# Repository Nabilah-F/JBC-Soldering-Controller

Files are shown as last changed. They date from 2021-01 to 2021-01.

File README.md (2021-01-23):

# JBC-Soldering-Controller

The idea of this project is to make a JBC soldering station for the T245, T210, HT420 and PA120 Micro Tweezers. 
It runs from a 12V to 24V DC power supply.

Tested:

T245 soldering iron

Todo:

Automatically changing the GUI depending on if you are using the standard iron or the tweezers.
Update FW to use tweezers.

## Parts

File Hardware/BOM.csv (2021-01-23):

Reference | Quantity | Value | Footprint | Datasheet
C1 C2 C4 C5 | 4 | 0.047uF | Capacitor_SMD:C_0805_2012Metric_Pad1.15x1.40mm_HandSolder | ~
C10 | 1 | 20uF | Capacitor_SMD:C_0805_2012Metric_Pad1.15x1.40mm_HandSolder | ~
C11 C14 C17 C18 C19 | 5 | 10nF | Capacitor_SMD:C_0805_2012Metric_Pad1.15x1.40mm_HandSolder | ~
C21 | 1 | 1uF | Capacitor_SMD:C_0805_2012Metric_Pad1.15x1.40mm_HandSolder | ~
C3 C6 | 2 | 0.47uF | Capacitor_SMD:C_0805_2012Metric_Pad1.15x1.40mm_HandSolder | ~
C7 C20 C9 C12 C13 C15 C16 | 7 | 0.1uF | Capacitor_SMD:C_0805_2012Metric_Pad1.15x1.40mm_HandSolder | ~
C8 | 1 | 10uF | Capacitor_SMD:C_0805_2012Metric_Pad1.15x1.40mm_HandSolder | ~
D1 | 1 | 1N4448 | Diode_SMD:D_SOD-123F | http://www.nxp.com/documents/data_sheet/1N4148_1N4448.pdf
D10 D11 D8 D9 | 4 | 4V7 | Diode_SMD:D_SOD-123 | ~
D2 | 1 | B140-E3 | Diode_SMD:D_SMA | http://www.vishay.com/docs/88946/b120.pdf
D3 D4 | 2 | WS2812B | LED_SMD:LED_WS2812B_PLCC4_5.0x5.0mm_P3.2mm | https://cdn-shop.adafruit.com/datasheets/WS2812B.pdf
D5 | 1 | LED | LED_SMD:LED_0603_1608Metric_Pad1.05x0.95mm_HandSolder | ~
D6 D7 | 2 | D | Diode_SMD:D_SOD-123F | ~
J1 J2 | 2 | JBC_iron | Connector_Phoenix_MSTB:PhoenixContact_MSTBVA_2,5_3-G-5,08_1x03_P5.08mm_Vertical
J3 J7 | 2 | Conn_01x01 | Connector_PinHeader_2.54mm:PinHeader_1x01_P2.54mm_Vertical | ~
J4 | 1 | Barrel_Jack_Switch | Connector_BarrelJack:BarrelJack_Horizontal | ~
J6 | 1 | Audio-Jack-3 | footprints:Jack_3.5mm_Horizontal
L1 | 1 | 22uH | Inductor_SMD:L_6.3x6.3_H3
Q1 Q2 | 2 | Q_NMOS_GSD | Package_TO_SOT_SMD:TO-263-2 | ~
R1 R2 R5 R6 | 4 | 100k | Resistor_SMD:R_0805_2012Metric_Pad1.15x1.40mm_HandSolder | ~
R13 | 1 | 52.3k | Resistor_SMD:R_0805_2012Metric_Pad1.15x1.40mm_HandSolder | ~
R14 R16 R19 R23 R24 R25 R26 R35 R36 | 9 | 10k | Resistor_SMD:R_0805_2012Metric_Pad1.15x1.40mm_HandSolder | ~
R15 | 1 | 0R | Resistor_SMD:R_0805_2012Metric_Pad1.15x1.40mm_HandSolder | ~
R17 R20 | 2 | 750R | Resistor_SMD:R_0805_2012Metric_Pad1.15x1.40mm_HandSolder | ~
R18 R21 | 2 | 1k2 | Resistor_SMD:R_0805_2012Metric_Pad1.15x1.40mm_HandSolder | ~
R22 | 1 | 330 | Resistor_SMD:R_0805_2012Metric_Pad1.15x1.40mm_HandSolder | ~
R27 R30 R31 R32 | 4 | 100 | Resistor_SMD:R_0805_2012Metric_Pad1.15x1.40mm_HandSolder | ~
R28 | 1 | 30k | Resistor_SMD:R_0805_2012Metric_Pad1.15x1.40mm_HandSolder | ~
R29 | 1 | 5k1 | Resistor_SMD:R_0805_2012Metric_Pad1.15x1.40mm_HandSolder | ~
R3 R4 R7 R8 | 4 | 820 | Resistor_SMD:R_0805_2012Metric_Pad1.15x1.40mm_HandSolder | ~
R33 R34 | 2 | DNF | Resistor_SMD:R_0805_2012Metric_Pad1.15x1.40mm_HandSolder | ~
R9 R10 R11 R12 | 4 | 51 | Resistor_SMD:R_0805_2012Metric_Pad1.15x1.40mm_HandSolder | ~
SW1 | 1 | Rotary_Encoder_Switch | footprints:rot_encoder_alt | ~
TP1 TP2 TP3 TP4 | 4 | TestPoint | TestPoint:TestPoint_Keystone_5005-5009_Compact | ~
U1 | 1 | OLED_I2C_128x32 | footprints:OLED_I2C_128x32_alt
U10 | 1 | 74LVC1G32 | Package_TO_SOT_SMD:SOT-23-5_HandSoldering | http://www.ti.com/lit/sg/scyt129e/scyt129e.pdf
U2 | 1 | arduino_pro_micro | Package_DIP:DIP-24_W15.24mm_LongPads
U3 | 1 | ADS1120-PW | Package_SO:TSSOP-16_4.4x5mm_P0.65mm | http://www.ti.com/lit/ds/symlink/ads1120.pdf
U4 | 1 | MCP16301 | Package_TO_SOT_SMD:SOT-23-6_Handsoldering
U5 | 1 | AD586 | Package_SO:SOIC-8-1EP_3.9x4.9mm_P1.27mm_EP2.35x2.35mm | http://www.analog.com/media/en/technical-documentation/data-sheets/AD586.pdf
U6 U7 | 2 | VN5E010 | footprints:HPAK
U8 U9 | 2 | FODM3011 | Package_DIP:SMDIP-4_W7.62mm | http://www.fairchildsemi.com/ds/FO/FODM3053.pdf

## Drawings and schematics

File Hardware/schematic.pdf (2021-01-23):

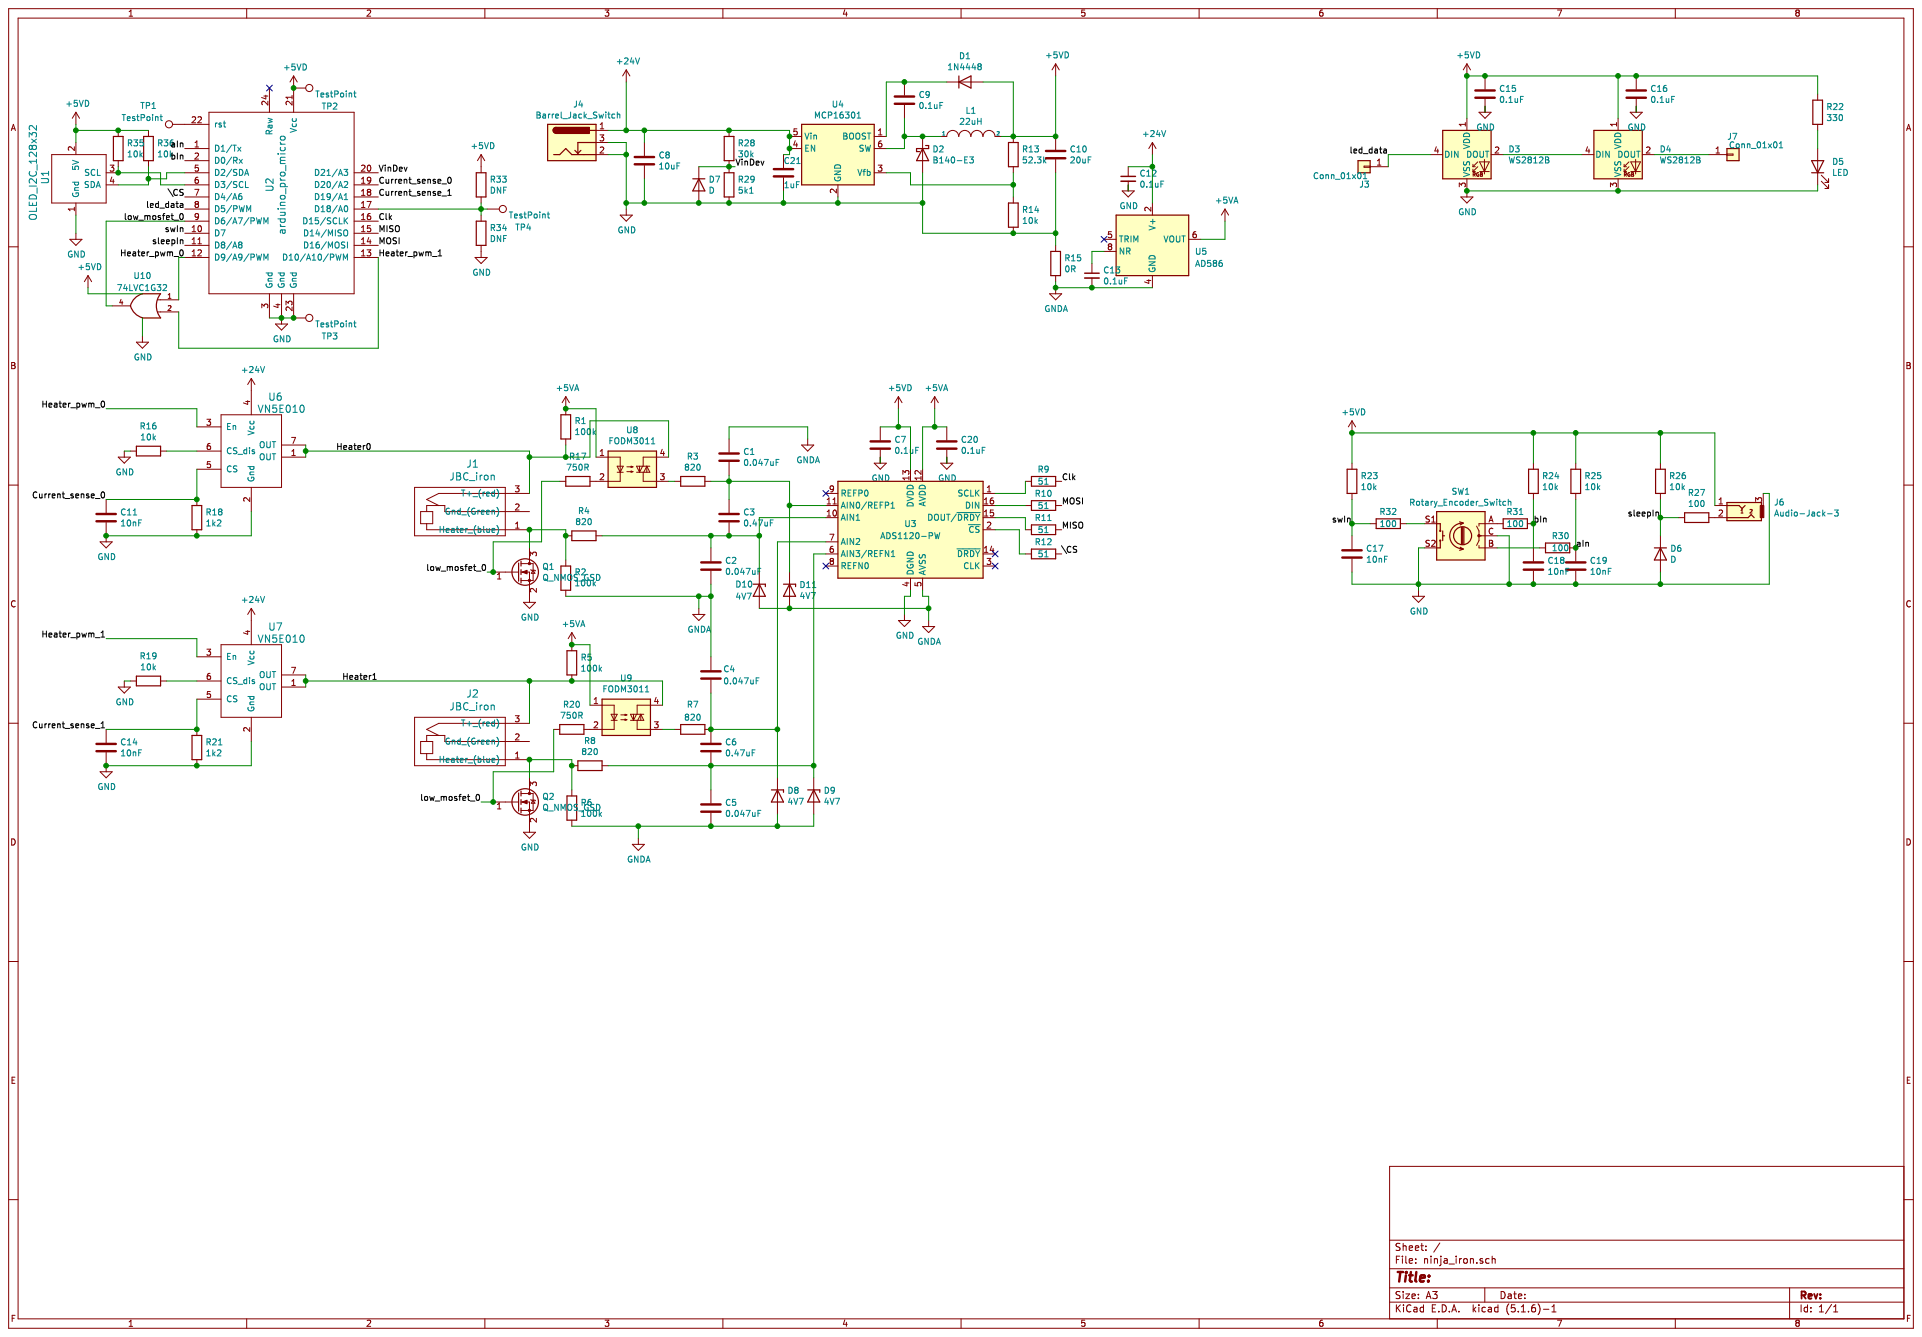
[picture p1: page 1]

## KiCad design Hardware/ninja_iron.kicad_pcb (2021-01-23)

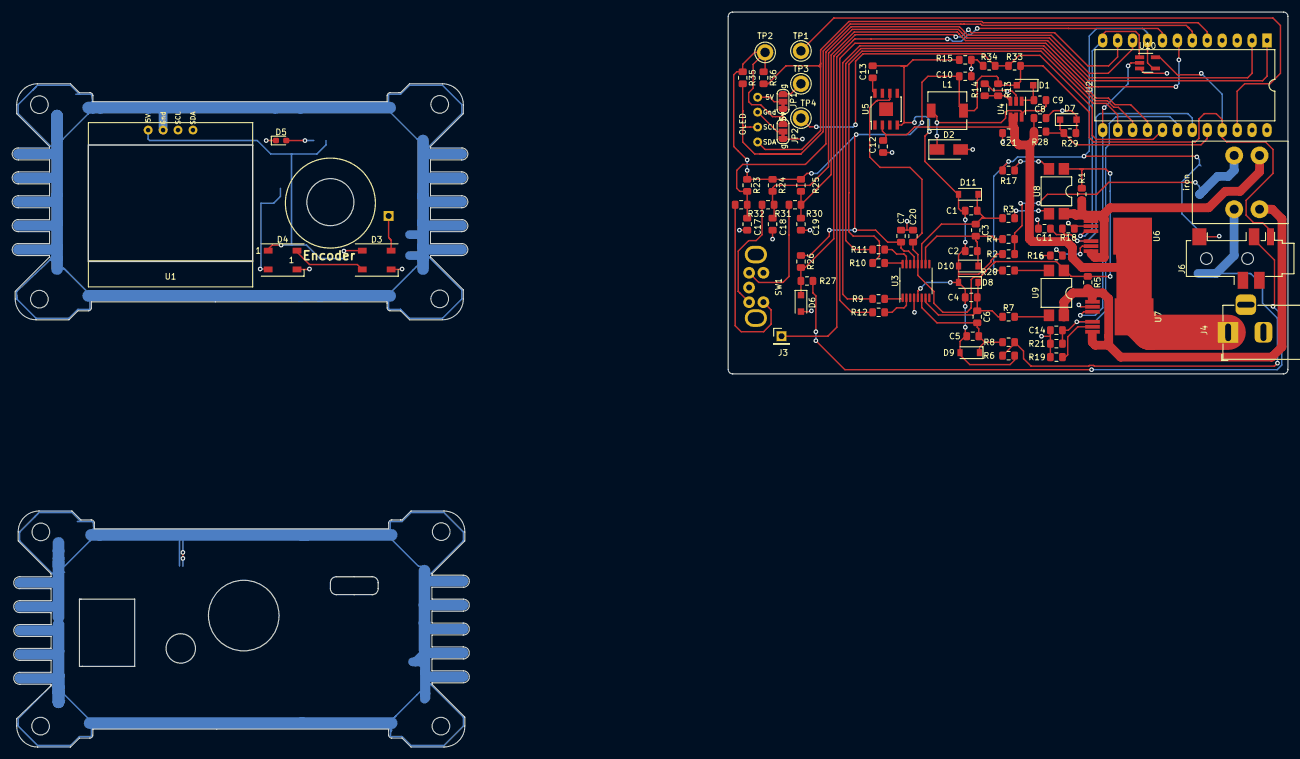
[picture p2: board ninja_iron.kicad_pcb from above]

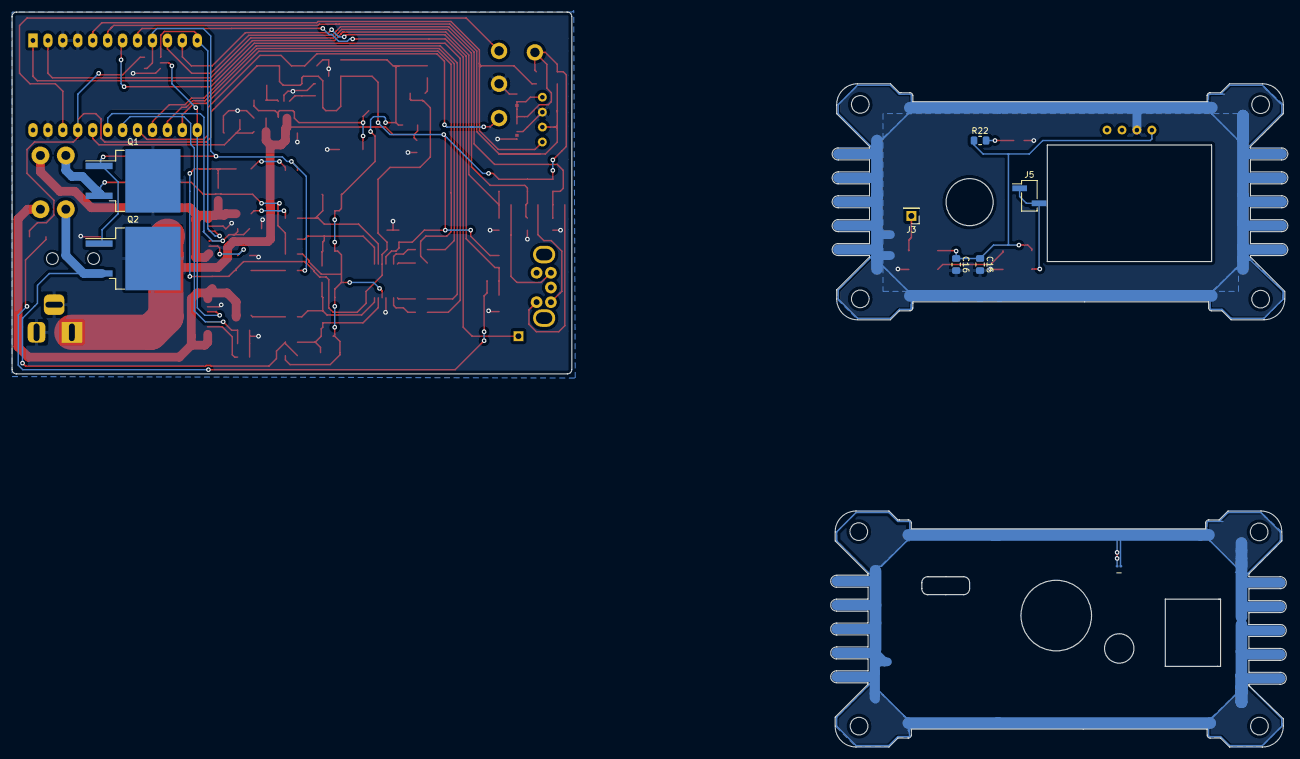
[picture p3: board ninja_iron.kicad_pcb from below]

Board: 2 copper layers, 95.2 x 61.5 mm, 96 parts (8 on the bottom side), 52 nets.

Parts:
-: R_0201_0603Metric
C1, C2, C4, C5: 0.047uF; C_0805_2012Metric_Pad1.15x1.40mm_HandSolder
C3, C6: 0.47uF; C_0805_2012Metric_Pad1.15x1.40mm_HandSolder
C7, C9, C12, C13, C15, C16, C20: 0.1uF; C_0805_2012Metric_Pad1.15x1.40mm_HandSolder
C8: 10uF; C_0805_2012Metric_Pad1.15x1.40mm_HandSolder
C10: 20uF; C_0805_2012Metric_Pad1.15x1.40mm_HandSolder
C11, C14, C17, C18, C19: 10nF; C_0805_2012Metric_Pad1.15x1.40mm_HandSolder
C21: 1uF; C_0805_2012Metric_Pad1.15x1.40mm_HandSolder
D1: 1N4448; D_SOD-123F
D2: B140-E3; D_SMA
D3, D4: WS2812B; LED_WS2812B_PLCC4_5.0x5.0mm_P3.2mm
D5: LED; LED_0603_1608Metric_Pad1.05x0.95mm_HandSolder
D6, D7: D; D_SOD-123F
D8, D9, D10, D11: 4V7; D_SOD-123
J3, J3#2: Conn_01x01; PinHeader_1x01_P2.54mm_Vertical
J4: Barrel_Jack_Switch; BarrelJack_Horizontal
J5: Conn_01x01; PinHeader_1x02_P2.54mm_Vertical_SMD_Pin1Left
J6: Audio-Jack-3; Jack_3.5mm_Horizontal
JP1, JP2: -; SolderJumper-3_P1.3mm_Bridged12_RoundedPad1.0x1.5mm_NumberL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
L1: 22uH; L_6.3x6.3_H3
OLED: pin_oled
Q1, Q2: Q_NMOS_GSD; TO-263-2
R1, R2, R5, R6: 100k; R_0805_2012Metric_Pad1.15x1.40mm_HandSolder
R3, R4, R7, R8: 820; R_0805_2012Metric_Pad1.15x1.40mm_HandSolder
R9, R10, R11, R12: 51; R_0805_2012Metric_Pad1.15x1.40mm_HandSolder
R13: 52.3k; R_0805_2012Metric_Pad1.15x1.40mm_HandSolder
R14, R16, R19, R23, R24, R25, R26, R35, R36: 10k; R_0805_2012Metric_Pad1.15x1.40mm_HandSolder
R15: 0R; R_0805_2012Metric_Pad1.15x1.40mm_HandSolder
R17, R20: 750R; R_0805_2012Metric_Pad1.15x1.40mm_HandSolder
R18, R21: 1k2; R_0805_2012Metric_Pad1.15x1.40mm_HandSolder
R22: 330; R_0805_2012Metric_Pad1.15x1.40mm_HandSolder
R27, R30, R31, R32: 100; R_0805_2012Metric_Pad1.15x1.40mm_HandSolder
R28: 30k; R_0805_2012Metric_Pad1.15x1.40mm_HandSolder
R29: 5k1; R_0805_2012Metric_Pad1.15x1.40mm_HandSolder
R33, R34: DNF; R_0805_2012Metric_Pad1.15x1.40mm_HandSolder
SW1: Rotary_Encoder_Switch; rot_encoder_alt
TP1, TP2, TP3, TP4: TestPoint; TestPoint_Keystone_5005-5009_Compact
U1: OLED_I2C_128x32; OLED_I2C_128x32_alt
U2: arduino_pro_micro; DIP-24_W15.24mm_LongPads
U3: ADS1120-PW; TSSOP-16_4.4x5mm_P0.65mm
U4: MCP16301; SOT-23-6_Handsoldering
U5: AD586; SOIC-8-1EP_3.9x4.9mm_P1.27mm_EP2.35x2.35mm
U6, U7: VN5E010; HPAK
U8, U9: FODM3011; SMDIP-4_W7.62mm
U10: 74LVC1G32; SOT-23-5_HandSoldering
iron: neutrik_modified

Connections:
+5VA: C20.1, R1.2, R5.1, U3.12, U5.6, U8.1, U9.1
+5VD: C7.1, C10.1, C15.1, C16.1, D1.2, D3.1, D4.1, J6.1, JP1.1, JP1.2, JP2.3, L1.2, OLED.1, R13.1, R22.1, R23.1, R24.1, R25.1, R26.1, R33.1, R35.1, R36.1, TP2.1, U1.1, U2.21, U3.13, U10.5
+24V: C8.1, C12.1, C21.1, J4.1, R28.1, U4.4, U4.5, U5.2, U6.4, U7.4
/Clk: R9.1, U2.16
/Current_sense_0: C11.1, R18.1, U2.19, U6.5
/Current_sense_1: C14.1, R21.1, U2.18, U7.5
/Heater0: R1.1, U6.1, U6.7, U8.4, iron.5
/Heater1: R5.2, U7.1, U7.7, U9.4, iron.3
/Heater_pwm_0: U2.12, U6.3, U10.1
/Heater_pwm_1: U2.13, U7.3, U10.2
/MISO: R11.1, U2.15
/MOSI: R10.1, U2.14
/VinDev: D7.1, R28.2, R29.1, U2.20
/\CS: R12.1, U2.7
/aIn: C19.1, R25.2, R30.1, U2.1
/bIn: C18.1, R24.2, R31.1, U2.2
/led_data: D3.4, J3.1, J3#2.1, U2.8
/low_mosfet_0: Q1.1, Q2.1, R17.2, R20.2, U2.9, U10.4
/sleepIn: D6.1, R26.2, R27.2, U2.11
/swIn: C17.1, R23.2, R32.2, U2.10
GND: -.1, -.2, C7.2, C8.2, C10.2, C11.2, C12.2, C14.2, C15.2, C16.2, C17.2, C18.2, C19.2, C20.2, C21.2, D2.2, D3.3, D4.3, D5.1, D6.2, D7.2, J4.2, J4.3, J6.3, JP1.3, JP2.1, JP2.2, OLED.2, Q1.2, Q2.2, R14.2, R15.1, R16.2, R18.2, R19.2, R21.2, R29.2, R34.2, TP3.1, U1.2, U2.3, U2.4, U2.23, U3.4, U4.2, U6.2, U7.2, U10.3
GNDA: C1.1, C2.2, C4.1, C5.2, C13.2, D8.2, D9.2, D10.2, D11.2, R2.1, R6.2, R15.2, U3.5, U5.4
unnamed: C1.2, C3.1, D11.1, R3.1, U3.11
unnamed: C2.1, C3.2, D10.1, R4.1, U3.10
unnamed: C4.2, C6.1, D8.1, R7.1, U3.7
unnamed: C5.1, C6.2, D9.1, R8.1, U3.6
unnamed: C9.1, D1.1, U4.1
unnamed: C9.2, D2.1, L1.1, U4.6
unnamed: C13.1, U5.8
unnamed: D3.2, D4.4
unnamed: D4.2, J5.1, J5.2
unnamed: D5.2, R22.2
unnamed: Q1.3, R2.2, R4.2, iron.4
unnamed: Q2.3, R6.1, R8.2, iron.2
unnamed: J6.2, R27.1
unnamed: R3.2, U8.3
unnamed: R7.2, U9.3
unnamed: R9.2, U3.1
unnamed: R10.2, U3.16
unnamed: R11.2, U3.15
unnamed: R12.2, U3.2
unnamed: R13.2, R14.1, U4.3
unnamed: R16.1, U6.6
unnamed: R17.1, U8.2
unnamed: R19.1, U7.6
unnamed: R20.1, U9.2
unnamed: R33.2, R34.1, TP4.1, U2.17
unnamed: U1.3, U2.6
unnamed: U1.4, U2.5
unnamed: TP1.1, U2.22
unnamed: OLED.3, R35.2
unnamed: OLED.4, R36.2

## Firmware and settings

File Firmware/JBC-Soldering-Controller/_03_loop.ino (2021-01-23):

/* Copyright (c) 2017 timothyjager
   JBC-Soldering-Controller
   MIT License. See LICENSE file for details.
*/

//----------------Main Loop------------------------
void loop(void)
{
  if(fastDigitalRead(LPINA)){
    vSense0 = analogRead(CURRENT_SENSE0)*0.00488;//5.0*analogRead(CURRENT_SENSE0)/1024.0;// read mosfet current
    vSense1 = analogRead(CURRENT_SENSE1)*0.00488;
    //if(fastDigitalRead(LPINA)){
      vInDev = analogRead(VIN_SENSE)*0.00488;// read power supply voltage
      params.tipResistance0 = (vInDev/vSense0)*1.1798;// * (1200.0/7000.0) * (35100.0/5100.0);// work out resistance of tip
      params.tipResistance1 = (vInDev/vSense1)*1.1798;
      //params.iron = ;
      if(params.tipResistance0 > 2.80 && params.tipResistance0 < 3.75){
        params.iron = iron_T245;
      }
      else if(params.tipResistance0 > 1.75 && params.tipResistance0 < 2.65){
        params.iron = iron_T210;
      }
      else if(params.tipResistance0 > 2.65 && params.tipResistance0 < 2.80){
        ;
      }
      else {
        params.iron = iron_none;
      }
    //}
  }
  //static bool in_cradle;
  bool update_display_now = false;

  //read the encoder knob
  static int16_t knob_pos_last = 0;

  status.encoder_pos = knob.read(); //>> 2;  //divide by 2 to decrease sensitivity

  //Check if knob has changed
  if (status.encoder_pos != knob_pos_last)
  {
    //Dont allow it to go negative.
    if (status.encoder_pos < 0)
    {
      knob.write(0);
      status.encoder_pos = 0;
    }
    else if(status.encoder_pos > upper_set_limit)
    {
      knob.write(upper_set_limit);
      status.encoder_pos = upper_set_limit;
    }
    params.setpoint = status.encoder_pos;
    if (myPID.GetMode() == AUTOMATIC)
    {
      status.pid_setpoint = params.setpoint;
    }

    update_display_now = true;  //refresh the screen more quickly while adjusting the knob
  }
  knob_pos_last = status.encoder_pos;

  //When button is pressed toggle power on/off
  if (fastDigitalRead(ENC_BUTTON) == false)
  {
    //noInterrupts();
    if (iron_active == true)
    {
      iron_active = false;
      params.pid_mode = MANUAL;
      myPID.SetMode(params.pid_mode);
      myPID2.SetMode(params.pid_mode);
      status.pid_output = 0;
      status.pid_output2 = 0;
      status.pid_setpoint = 0;
      cradle_present=false;
    }
    else
    {
      iron_active = true;
      params.pid_mode = AUTOMATIC;
      myPID.SetMode(params.pid_mode);
      myPID2.SetMode(params.pid_mode);
      status.pid_setpoint = params.setpoint;
    }
    //interrupts();
    delay(200);
    while (fastDigitalRead(ENC_BUTTON) == false)
    delay(200);
  }


  //When on cradle power on/off
  if (fastDigitalRead(CRADLE_SENSOR) == false)
  {
    cradle_present = true; //we have deteected a cradle is being used. So from now on, we respond to on/off cradle events.
    //noInterrupts();
    if (params.pid_mode == AUTOMATIC)
    {
      params.pid_mode = MANUAL;
      myPID.SetMode(params.pid_mode);
      myPID2.SetMode(params.pid_mode);
      status.pid_output = 0;
      status.pid_setpoint = 0;
    }
    //interrupts();
  }
  else if(fastDigitalRead(CRADLE_SENSOR) == true && cradle_present && iron_active)
  {
      //noInterrupts();
      params.pid_mode = AUTOMATIC;
      myPID.SetMode(params.pid_mode);
      myPID2.SetMode(params.pid_mode);
      status.pid_setpoint = params.setpoint;
      //interrupts();
  }

  ProcessSerialComm();
  updateDisplay(0);
  updateLEDStatus();
}

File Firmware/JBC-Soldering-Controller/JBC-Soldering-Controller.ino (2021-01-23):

/* Copyright (c) 2017 timothyjager
   JBC-Soldering-Controller
   MIT License. See LICENSE file for details.
*/

#include <SPI.h>
#include <Wire.h>
//#include <EEPROM.h>
//#include <Adafruit_NeoPixel.h>

#include <Adafruit_GFX.h>       //https://github.com/adafruit/Adafruit-GFX-Library
#include <Adafruit_SSD1306.h>   //https://github.com/adafruit/Adafruit_SSD1306
#include <Encoder.h>            //https://github.com/PaulStoffregen/Encoder
#include <TimerOne.h>           //https://github.com/PaulStoffregen/TimerOne
#include <DigitalIO.h>          //https://github.com/greiman/DigitalIO
//#include <dell_psu.h>           //https://github.com/timothyjager/DellPSU
//#include <EEWrap.h>             //https://github.com/Chris--A/EEWrap
#include <PID_v1.h>             //https://github.com/br3ttb/Arduino-PID-Library/
#include <NeoPixelBus.h>

#include <MsTimer2.h>
